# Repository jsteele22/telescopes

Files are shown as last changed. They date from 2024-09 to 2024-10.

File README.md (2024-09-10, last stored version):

# Notes on using CC portable telescopes.

There are many possible combinations of equipment that can be used
together; eg, tripod, mount, OTA, camera,...

The approach used here will be to document each item in separate
pages.  For a given combination of equipoment, a \"manual\" can be
constructed by combining the relevant pages.

A few standard combinations are presented here.

## Mounts with Field Tripods

* [Skywatcher EQ6-R Pro](docs/mount/eq6.md)
* [Losmandy G11](docs/mount/losmandy.md)
* [Celestron](docs/mount/celestron.md)

## Optical Tube Assemblies (OTAs)

* [Celestron 8\"](docs/ota/celestron8.md)
* [Meade 8\"](docs/ota/meade8.md)
* [Meade 10\"](docs/ota/meade10.md)
* [Lunt Solar telescope](docs/ota/lunt.md)

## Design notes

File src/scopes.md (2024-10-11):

# Portable Telescopes

## Standalone telescopes
Simple all-in-one approach.

* [UniStellar eVscope](standalone/evscope.md)
* [Dobsonian Telescopes](standalone/dobs.md)

## Component Telescopes
Combine components to form a complete system.

* An [optical tube assembly (OTA)](otas/index.md) gathers and focuses the light.
* A [mount](mounts/index.md) points the OTA in the right direction.
* A [pier adapter](pier/index.md) alows a mount to be used on a fixed pier.

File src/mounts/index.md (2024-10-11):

# Telescope Mounts

The following mounts are available.  Each includes a tripod for field
use and a pier adapter for use on our observatory deck.

* [Skywatcher EQ6-R Pro](eq6/index.md) The newest mount, and best
  choice for general purpose use.  This mount has a USB port and can
  be controlled by a Windows computer or the hand controller.

* [Losmandy G11](losmandy/index.md) The strongest of our mounts and
  very well made.  This mount has a custom stepper motor system and an
  open-source (**OnStep**) controller.

* [Celestron EQ5](eq5/index.md) (aka EQ5) An older, lighter-weight
  mount. This mount has a custom stepper motor system and an
  open-source (**OnStep**) controller.
  
## Using OnStep

Two of the above mounts have **OnStep** control systems.  Since the
systems are very similar, they will be [explained together
here](using_onstep/index.md).

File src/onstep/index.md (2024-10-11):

# OnStep

**Onstep** is an open source hardware/software project to provide
smart telescope features (e.g., alignment, GoTo) to an otherwise
un-smart or even unmotorized telescope.

For general information about OnStep, go to [the OnStep project
homepage](http://onstep.groups.io/g/main/wiki/3860).

Two of our telescope mounts have been converted for use with
OnStep. Information regarding these particular OnStep conversions is
provided here:

* Details that are [common to both mounts](shared/index.md) 

* Details specific to the [Losmandy G11](g11/index.md) mount

* Details specific to the [Celestron EQ5](eq5/index.md) mount.

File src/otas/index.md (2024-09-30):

# Optical Tube Assemblies
All of these OTAs have a an aluminum dovetail bar that mates with any
of our mounts.

### [Lunt H-alpha](lunt/index.md)
A dedicated solar telescope.

### [Celestron 8"](c8/index.md)
Our newest and best optical telescope.

### [Meade 8"](meade8/index.md)
OTA removed from an old Meade LX200.

### [Meade 10"](meade10/index.md)
OTA removed from a an old Meade LX200.

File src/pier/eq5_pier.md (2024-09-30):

# Pier Adapter for Celestron EQ5 Mount.

The EQ5 mount is *much* sturdier on a pier than on it's tripod!

## Required

The following items are stored in the glass case by the Observatory
double doors:

* EQ5 **Pier Adapter**: a cylinder of unfinished aluminum, with a
  protruding tab on top.

* EQ5 **Pier Adapter Rod**: A chromed metal rod with threads on one
  end and an aluminum knob on the other.

## Setup

* Place the adapter above the large hole towards the northern end of
  the pier shelf.

* Orient the adapter so that the **azimuth adjustment post** on top is
  to the North.

* Try inserting the theaded end of the adapter rod through the large
  hole on the underside of the pier shelf. With the rod perfectly
  vertical, it should pass upwards through the very center of the pier
  adapter.

* Look at the base of the EQ5 mount and locate the the pair of screws
  with black plastic knobs. These are the **azimuth adjustment
  screws.**

* Look at the underside of the EQ5 mount an loosen both screws until
  there is plenty of space between them: an inch or 2-3 cm is good.

* Gently place the EQ5 mount on the pier adapter, being sure that the
  tips of the azimuth adjustment screws pass on either side of the
  azimuth adjustment post.

* As before, pass the threaded pier adapter rod from below the pier
  shelf up through the adapter and get it threaded into the mount.

* Screw in the rod until it is close but not all the way in.

* Slowly start to tighten the rod, being sure to wiggle the
  adapter/mount slighly. It is important that the adapter centers
  itself and all parts are vertically aligned.

* Tighten the rod until it is **snug, but not tight**.

Everything else follows the normal setup and alignment procedures for
the mount.

## Takedown

Be sure to return the Pier Adapter and the threaded Pier Adapter Rod to their
correct storage spot: the glass case by the double doors of the
observatory.

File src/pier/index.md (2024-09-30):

# Pier mountings

Just outside the double doors of the Barnes Observatory is a metal
pier that can be used instead of a tripod with some of our telescope
mounts.

The only difference from normal (tripod) use of the mount lies in the
special adapter needed.

* [Losmandy Pier Adapter](losmandy_pier.md)
* [Celestron EQ5 Pier Adapter](eq5_pier.md)

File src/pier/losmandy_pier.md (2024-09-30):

# Pier Mount for Losmandy G11 Mount.

This is a great combination: our sturdiest mount on our sturdiest support.

## Required :

These should all be stored together in the glass case by the double
doors of the Observatory:

* The Losmandy pier adapter (black anodized aluminum.)
* Threee hex screws **kept with the pier adapter at all times.**
* T-handle hex driver **kept with the pier adapter at all times.**

## Setup:

* Line the adapter up with the appropriate threaded holes in the
  pier. The little tabs for mounting the control electronics should
  point to the South.

* Get all 3 screws started.

* Screw all 3 screws to just barely touching the bottom.

* Tighten all 3 screws a **little bit snug.**

* Return the T-handle hex driver to its storage place.

The adapter is identical to the top of the Losmandy tripod, so
remainder of setup proceeds as usual.

## Takedown

* Remove the three screws.

* Return the adapter, the three screws, and the T-handle nut driver to
  their storage place.

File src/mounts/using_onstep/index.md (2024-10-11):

# Using OnStep

## Why are you here?

Do you **need** to know anything about OnStep?

Our two OnStep telescope mounts are configured to begin tracking at
sidereal rate as soon as they are powered on.  If you don't plan to
use any smart telescope features like software star alignment or
finding a target, then you cn skip the rest and start observing.

Just point the telescope at an object.  If you were precise enough
while setting up the mount, the object should remain in view for a
while.

For everyone else, keep reading.

## Background

The most basic functions of the OnStep controller attached to the
telescope are:

* **Star Alignment:** gathering data on where the stars *really* are,
  and using this data to correct for imperfect mount alignment or
  configuration inputs.

* Keeping track of the telescope's position as it moves.

* Moving the scope, either in response to user input or to track
  objects as they move across the sky.

* Communication, whether it be with other electronics, a computer
  program, or even a human.

There are *many, many* ways to access and use OnStep.  Here we will
present a limited range of options to keep things manageable. Even so,
it helps to scan the material first to get a broad overview and then
decide where to focus for more detail.

Broadly speaking, you can connect to the telescope (i.e., the OnStep
controller) in two different modes.  This is not official OnStep
terminology, just a distinction that helps organize your approach to
using Onstep.

* **User Mode**, where a generic program (e.g., Stellarium) talks to
  the scope, but with limited features. This could even include
  simplistic use cases like a passive hand controller.

* **Control Mode**, where an OnStep-specific program has full control
  of (nearly) every possible feature.

Example: Stellarium is a great *user mode* program.  In addition to
its planetarium features, it can control and display the scope's
position and send data to the scope to update its star alignment.
This is almost all you need for a night of observing.  But Stellarium
cannot, for example, turn tracking on/off, switch to solar tracking,
park the telescope, change the slew rate, verify or change the time,
etc.  For that you will need a *Control Mode* program.

Note: It is fine to use different devices for control mode and user
mode access; e.g, an Android phone for control and a laptop for a user
program.  It is fine if both devices are connected simultaneously, but
they don't have to be; you could adjust a few settings from your phone
and then disconnect, then fire up software on your laptop for the rest
of the evening.

## Prerequisites (all use cases):

* The mount is set up and mechanically aligned.

* The OTA is installed and balanced.

* With **power off**, the scope is placed (precisely!) in **Home
  Position**.

## Power Up

Now, power on the controller.  There is no switch, just plug in the
power cable.

From now on, **do not move the scope manually** (i.e., by loosening
the clutches and pushing).  This would confuse the controller.

If anything goes wrong (power glitch, someone moves the cope manually)
just go back to Home position and do a power cycle.

## Establish Control Mode Access.

Choose one of the [options for Control Mode Access](control_mode.md)

## Are You Through Yet?

You might be ready to start observing.  There are a few options for
controlling the telescope without any additional software.

* You can just slew to objects you see in the sky.  For the slewing
  controls, you can use the web interface, the Android app, or a
  passive hand controller. (Check for hand controller directions
  before pluging anything in!)

* You can just enter coordinates for objects you want to observe using
  the web interface or the Android app. When you are centered on an
  object, you can update the star alignment.

* You can choose objects from a catalog in the Android app.  (The web
  interface also has this feature, but it needs updating to work.)

* A smart hand controller could be an option.  We don't have one yet,
  but stay tuned.

For anything more than the (not very polished) solutions above, you'll
probably want to use some user-friendly software.

## Prepare OnStep for User Mode Software.

Learn about [how user mode software talks to OnStep.](user_mode.md)
There may or may not be some steps you need to take.

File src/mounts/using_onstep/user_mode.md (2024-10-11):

# User Mode Software: Connecting to OnStep

To connect user mode software to OnStep, there are two choices to be
made:

## Hardware Connection : USB or WiFi

You have already seen how to connect to OnStep using WiFi.  You can
just use that method if it works for you.

But for User Mode connections, there is a new, much simpler option:
Just use a USB cable.  In my experience, this is by far the simplest
and most reliable method.

The USB connection works for Window, Linux, and Mac. For your OS, be
sure you know how to identify the connection after the cable is pluged
in.

## Software Connection : Direct, ASCOM, (INDI/INDIGO ?)

### Direct Serial Connection

If you are using a USB cable, then the OnStep controller acts just
like a Meade LX200 telescope.  This is an old, very popular telescope
and many user programs (including Stellarium) know how to talk
directly to it.

If you are using a Mac, this is the option for you.

### Using ASCOM

ASCOM is a software platform (**for Windows only**) that makes
astronomy programs work together.  Any user program (like Stellarium)
that supports ASCOM, will work with any instrument that supports
ASCOM; this includes not only our OnStep mounts, but also our
Skywatcher EQ6-R Pro mount, and other goodies as well (focusers,
cameras, ...)

With OnStep, ASCOM provides access to many more features, meaning less
need to mess around with control mode software.

If you plan to use your Windows computer with a telescope more than
one time, I recommend that you [set up ASCOM on your
computer.](ascom_setup.md)

### INDI/INDIGO

INDI and INDIGO are two identical-ish alternatives to ASCOM.  The goal
is to make something that works on any computer. It/they are much
newer and much more ambitious than ASCOM, so there seem to be more
rough edges and hiccups.

There are reports that it works with MacOS/Stellarium/OnStep.
However I have never tried this.

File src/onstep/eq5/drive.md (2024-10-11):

# Drive System for the EQ5 Mount

## Description

The DC gearmotors that came with the mount were removed. For each
axis, this left a worm drive with a ratio of 144:1.  This ratio is
still a bit high for fine control, so a further reduction was
introduced using toothed fan belts and pulleys. Using commonly
available pulleys with 16 and 60 teeth, 400-step stepper motors, and
16 microsteps, the final drive ratio is:

[(60/16) \* 400 \* 16 \* 144]/360 = 9600 microsteps per degree of axis rotation

## Details

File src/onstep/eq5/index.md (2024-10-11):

# Celestron EQ5 Onstep Conversion

## Background 

Our Celestron mount was purchased with the model name AS-GT. This
rather short-lived model was identical to the widely known EQ5 mount,
with the addition of a GoTo system.  Unfortunately, the AS-GT
electronics self-destructed during a firmware upgrade, so our mount
essentially became an EQ5.

## Drive Drain Description

For both axes, the drive train consists of a 400-step NEMA 17 stepper
motor, a right-angle NEMA 17 mounting bracket, and a belt drive
reduction consisting of GT2 standard 6mm wide timimng belt and pulleys.

Using 16 and 60 teeth pulleys, the 144:1 gear reduction of the worm
drives, and 16 microsteps per step gives us:

[400 \* 16 \* (60/16) \* 144]/360 = 9600 microsteps per degree of axis rotation.

## Adapters

Attaching drives to the EQ5 mount, which was not originally designed
to be motorized, is a bit tricky.  In this design, we use stock
right-angled motor mounts and a custom 3D printed adapter. For each
axis the adapter is different and the length of the timing belt is
different.  The adapters take advantage of existing holes in the EQ5
mount; no orinal hardware was modified.

The drive system was designed in OpenSCAD.  The [OpenSCAD source
code](Celestron_ASGT.scad) is used to generate the STL files for the
[RA adapter](eq5_ra_plate.stl) and the [Dec adapter](eq5_dec_plate.stl).

For the electrical connection to the motors, a housing was designed to
hold an RJ45 breakout board to the rear end of the motor. As before,
the [OpenSCAD source file](nema_cap.scad) was used to generate the
[STL file](nema_cap.stl) for 3D printing.

## Purchased Parts

All of the following purchased on Amazon.

* [NEMA 17 stepper motor](stepper.pdf)
* [NEMA 17 right angle bracket](bracket.pdf)
* GT2 pulley, 6mm wide, 16 teeth, 5mm bore
* GT2 pulley, 6mm wide, 60 teeth, 6mm bore
* GT2 timing belt, 6mm width, 180mm length, 90 teeth. (Declination) 
* GT2 timing belt, 6mm width, 158mm length, 79 teeth. (RA)

##  Additional upgrades to the EQ5 mount

* 3D printed [upper cover](eq5_polar_cover_upper.stl) for the polar scope.

* 3D printed [lower cover](eq5_polar_cover_lower.stl) for the polar scope.

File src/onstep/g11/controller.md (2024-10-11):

# MaxPCB4 Controller, Losmandy G11 details

The Losmandy mount uses the MaxPCB4 controller board.  This board is
configured as follows

* Teensy 4.1 microcontroller.

* TMC 2130 V3.0 motor driver modules (Amazon) for RA and Dec. These
  axes have RJ45 (e.g. Ethernet) socket outputs.  Conection to the
  corresponding stepper motors is via standard RJ$% patch cables.

* Two addional axes (focuser, etc.) not currently implemented.

* **Put a link to software config.**

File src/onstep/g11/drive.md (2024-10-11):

# Losmandy G11 Drive System.

## Background

On the stock G11, each axis had a DC gearmotor coupled to a worm gear
drive. The worm gear ratio is 360:1; i.e., a complete revolution of
the motor outut rotates the axis by 1 degree.

For the OnStep conversion, the original motors and couplers were
removed and the new NEMA 17 stepper motors installed using custom 3D
printed adapters. No physical modifications were made to the mount.

**Note**: The stepper motor take 400 full steps per revolution.  They are
run at 256 microsteps per step.  Thus, the final drive ratio is :

(400 \* 256 \* 360)/360 = 102400 microsteps per degree of axis
revolution.

## Worm Drive Coupler

The new stepper motors have a 5mm D output shaft.  The Losmandy worm
drive has a 1/4' (6.35 mm) input shaft.  For this application a
flexible coupler was purchased from Amazon. ("5mm to 6.35mm Shaft
Coupling 25mm Length 18mm Diameter")

Although the shaft diameters of this coupler are correct, the OD of
the coupler (18mm) is too large to enter the Losmandy worm gear
housing.  Thus, on the 1/4" end of the coupler, the OD had to be
machined down a bit  for clearance.

**Note**: Fasteners on the Losmandy mount are *inch*, not metric.

**Note** Each worm drive is protected by a rectangular cover. These
  can be removed using a 1/16" hex wrench to *loosen* (not remove) two
  tiny set screws. **Do not** loosen or adjust any other part of the
  worm drive system!

## Motor Adapters

The stepper motors are attached to the G11 using 3D printed adapters.
The adapters use the same threaded holes in the G11 mount as the old
motors.

In addition to positioning the stepper motors, the adapters provide an
enclosure for a small RJ45 breakout PCB purchased on Amazon. (Teansic
5 PCS RJ45 Connector Breakout Board 8-pin Headers Network Port
Adapter).  The stepper wire to RJ45 pin mapping matches the RJ45 ports
on the MaxPCB4 OnStep controller.

## Motor Adapter Design.

The adapters were designed in OpenSCAD. The .scad files contain the
source code for the design.  The OpenSCAD program is used to generate
.stl files for 3D printing.

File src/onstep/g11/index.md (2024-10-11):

# Losmandy G11 OnStep Conversion

## Background

Our Losmandy G11 mount came with feeble DC gearmotors that were
intended only for for.  The mount could neither slew nor perform
GoTo moves.  There was no means of keeping track of celestial
coordinates.

The addition of powerful stepper motors made it possible to control
the mount using OnStep.

# Details

Information pertaining to the G11 OnStep conversion:

* The [NEMA 17 stepper motors](17HM19-2004S.pdf) used for the G11 mount.

* The [motor drive system](drive.md), including info on 3D
  printed parts

* [CAD files](CAD/index.md) for 3D printed parts.

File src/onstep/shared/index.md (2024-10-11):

# OnStep Conversion Details

## TO DO: decide on V_in and Voltage regulation.

The following information pertains to the OnStep conversion of both
the Losmandy G11 and Celestron EQ5 mounts.

## The Firmware: OnStepX

The heart of OnStep is the firmware.  As the OnStep project matured, a
bottom-up re-write of the firmware called **OnStepX** was released.
This is the firmware we use.  Don't confuse it with the older
firmware, called simply OnStep.

For the purposes of configuring and building OnStepX for our telescope
mounts, I made a fork of the OnStepX github repository.  That repo can
be found [HERE](https://github.com/jsteele22/OnStepX), and should be
consulted for any further firmware details.

## The Controller: MaxPCB4

The firmware must run on a *dedicated* microcontroller which can
directly control the motors on the mount.  So the other heart of
OnStep is a **controller board** which at minimum provides a
microcontroller, at least two motor drivers, and some means of
communication with the user.

There are many different controller boards available which meet these
requirements.  The one we use is the **MaxPCB4**.  This board was
designed specifically for the OnStep project and it only runs the
OnStepX firmware.

Some public information about the MaxPCB4:

* [General information ](http://onstep.groups.io/g/main/wiki/33523)

* [PCB design](http://oshwlab.com/hdutton/maxpcb4/)

* [Kits for sale here](http://graydigitalarts.com/product/maxpcb4)

# Controller Hardware Options

There are various hardware options when assembling the MaxPCB4
controller.  Below are the *hardware* configuration we currently have.
For firmware configuration options, see the github repository
referenced above.

* PCB version : MaxPCB4.01

* Microcontroller module: Teensy 4.1

* Battery backup option: installed.

* Power switch: no

* Axes 1 and 2 (Ra, Dec) motor controllers : TMC2130 v3.0 modules
  purchased from from vendor BIQU on Amazon. These are SPI
  controllers.

* Axes 1 and 2 jumpers: set for SPI mode

* Axes 1 and 2 (RA, Dec) output connector: RJ45.

* Axes 3 and 4 motor controller: not installed (yet)

* Axes 3 and 4 jumpers: not populated.

* Axes 3 and 4 output connector: RJ22 (6P6C modular jack.)

* Axes 3 and 4 voltage: same as Axes 1 and 2.

* DB15 auxilliary connector:  not populated.

* ST4 interface: RJ12 socket installed, +5V jumper **not** installed.

* WeMos D1 socket : ESP8266 WeMos Mini Pro (provides WiFi, no
  Bluetooth.) Currently running the OnStep Smart Web Server (SWS)

* Buzzer: not installed. (requires *active* piezo buzzer.)

## Potential Hardware Configuration Changes:

* Use Axis 3 (or 4) to control focuser on Lunt solar telescope.

* Install an active buzzer.

* Replace Wemos module with WeMos ESP32 D1 Mini, to provide Bluetooth
  capability.

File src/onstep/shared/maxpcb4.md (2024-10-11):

# MaxPCB4 Onstep Controller Board.

Many different controller boards can run OnStep firmware.  The
specific one used for our mounts is the
[MaxPCB4](http://oshwlab.com/jdutton/maxpcb4).

More info to go here eventually.

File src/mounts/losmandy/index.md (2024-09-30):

# Losmandy G11

The Losmandy G11 is an exremely well-made and strong mount. It is
great when using telescope with a camera.

The extremely limited controller that came with this mount has been
replaced with more powerful stepper motors and an OnStep controller
that allows for computer control.

* [packing](losmandy_packing.md)
* [setup](losmandy_setup.md)

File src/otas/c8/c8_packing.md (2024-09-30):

# Packing List: Celestron 8" OTA

* Pelican case with OTA.
* 2" Star Diagonal in original box.  (Posisbly inside Pelican case.)
* Appropriate 2" eyepieces.

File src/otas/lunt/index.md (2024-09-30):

# Lunt H-alpha Solar Telescope

A small refractor telescope with an extremely sharp, tunable filter
for observing the Suns H-alpha line.

* [Packing List](lunt_packing.md)
* [Setup](lunt_setup.md)
* [Usage](lunt_usage.md)

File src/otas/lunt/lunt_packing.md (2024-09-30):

# Packing List for Lunt Solar OTA

The following items should be in the aluminum case:

* Lunt H-alpha OTA
* metal lens cover, screwed into OTA
* _Sol Searcher_ finder, atached to OTA
* Diagonal _B1200_, attached to OTA
* aluminum dovetail bar, attached to OTA
* 1-1/4" eyepieces: 10mm, 25mm
* black cloth to cover head

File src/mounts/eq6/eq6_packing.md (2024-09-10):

# Packing List : Skywatcher EQ6-R Pro

## Items to Pack:

* White tripod
* 2 white counterweights.
* Goal Zero power bank (Only usable power source ATM...)
* Pelican case with mount and accessories.

## Contents of Pelican Case:

* EQ6-R Pro mount
* Spider (stored vertically, in front of case.)
* 2x Azimuth adjuster bolts
* Hand controller with cord.
* Power cord.

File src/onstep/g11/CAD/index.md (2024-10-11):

# CAD Files for G11 OnStep Conversion

## Stepper Motor Adapters

The stepper motor adapters were designed in OpenSCAD. Here is [the
OpenSCAD source code](losmandy1.scad) and here are the [STL
files](mount_stl/index.md).

## Controller Board Enclosure

The MaxPCB4 controller is enclosed in a housing which attaches to the
G11 mount in the same way as the original controller.

It was designed using [OnShape](http://www.onshape.com), a free web-based CAD
program.  Here are the [STL files](enclosure_stl/index.md) for the enclosure.

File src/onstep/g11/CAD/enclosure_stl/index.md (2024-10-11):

# STL files for MaxPCB4 enclosure, Losmandy version

* [base](losmandy_base.stl)
* [lid](losmandy_lid.stl)
* [left panel](losmandy_panel_l.stl)
* [right panel](losmandy_panel_r.stl)
* [plug for nut](losmandy_plug.stl)

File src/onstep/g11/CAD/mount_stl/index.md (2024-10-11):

# Stepper Motor Mounts for Losmandy G11

* [adapter plate](losmandy1_plate.stl)
* [cover](losmandy1_cover.stl)

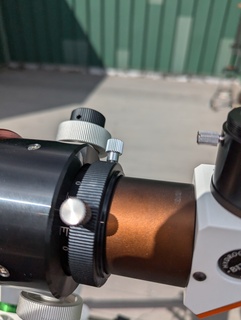
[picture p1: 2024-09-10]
src/media/pub/lunt_ota_extended.jpg

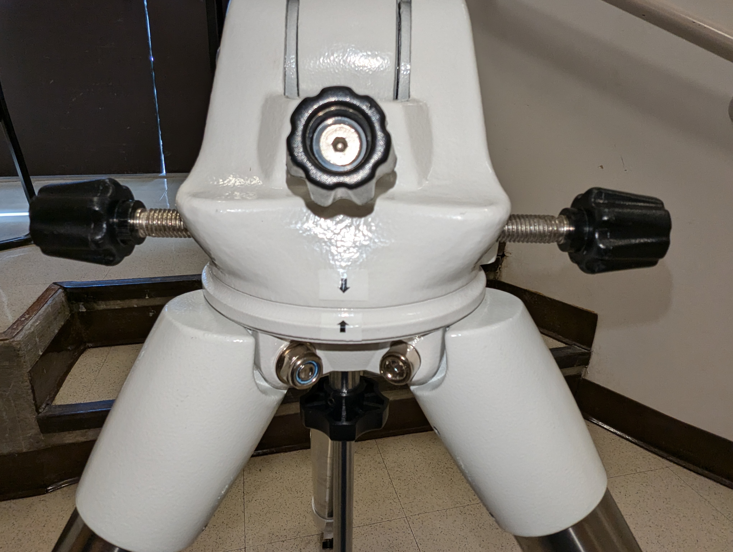
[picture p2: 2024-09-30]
mkdocs_astro/website_src/media/incoming/.trashed-1728593634-PXL_20240910_205335041.jpg

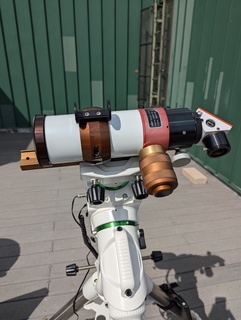
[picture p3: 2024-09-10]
src/media/pub/lunt_ota_mounted.jpg

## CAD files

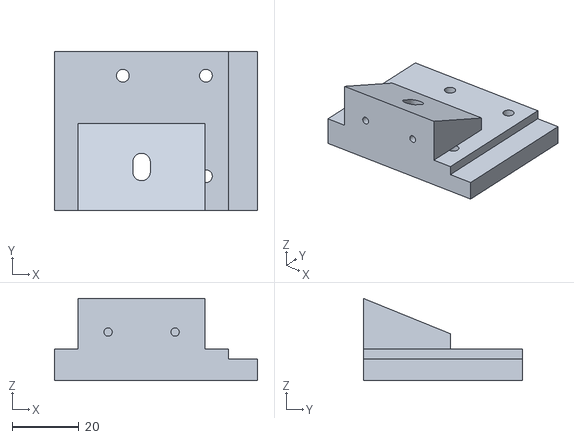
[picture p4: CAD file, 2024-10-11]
src/onstep/eq5/eq5_ra_plate.stl
60.6 x 47.5 x 24.5

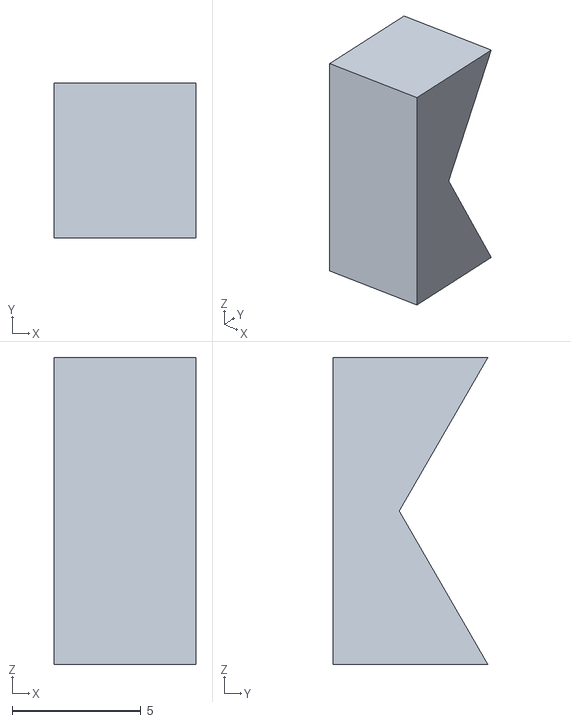
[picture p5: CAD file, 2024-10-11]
src/onstep/g11/CAD/enclosure_stl/losmandy_plug.stl
5.50 x 6.00 x 11.9

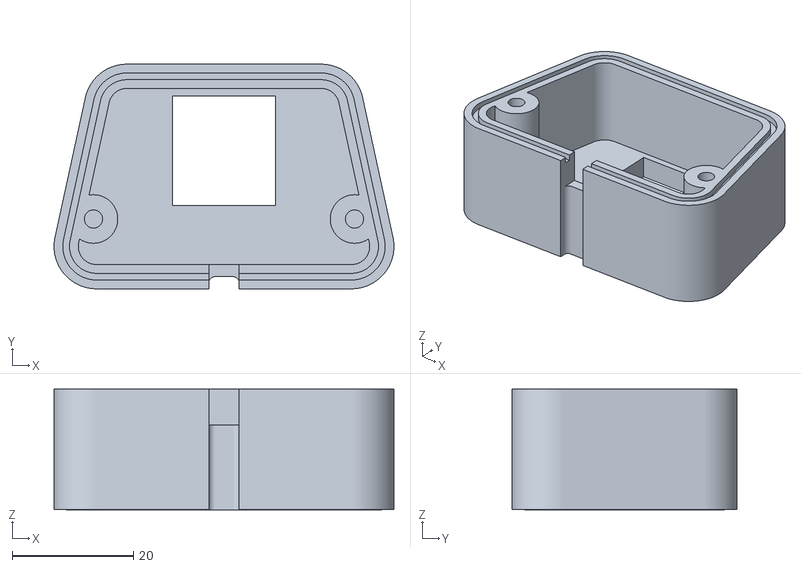
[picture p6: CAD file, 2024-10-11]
src/onstep/g11/CAD/mount_stl/losmandy1_cover.stl
56.0 x 37.0 x 19.9

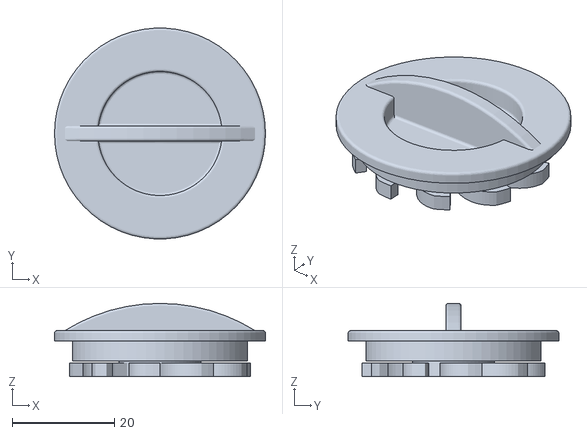
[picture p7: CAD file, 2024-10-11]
src/onstep/eq5/eq5_polar_cover_upper.stl
41.2 x 41.2 x 14.3

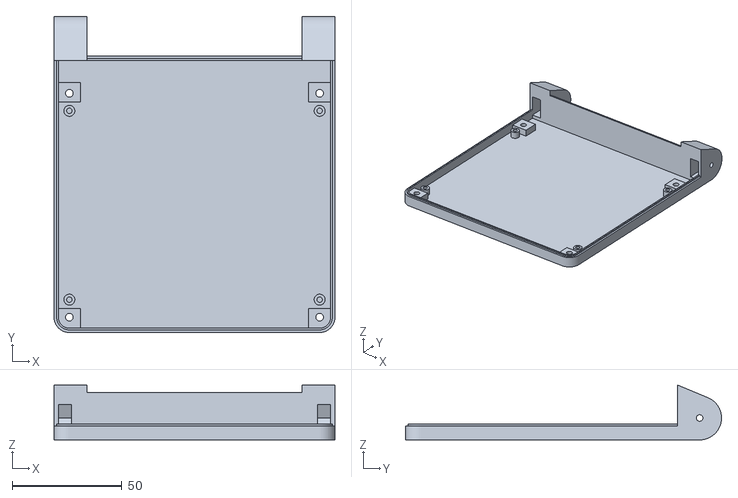
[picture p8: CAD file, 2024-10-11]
src/onstep/g11/CAD/enclosure_stl/losmandy_base.stl
128.0 x 144.0 x 25.0

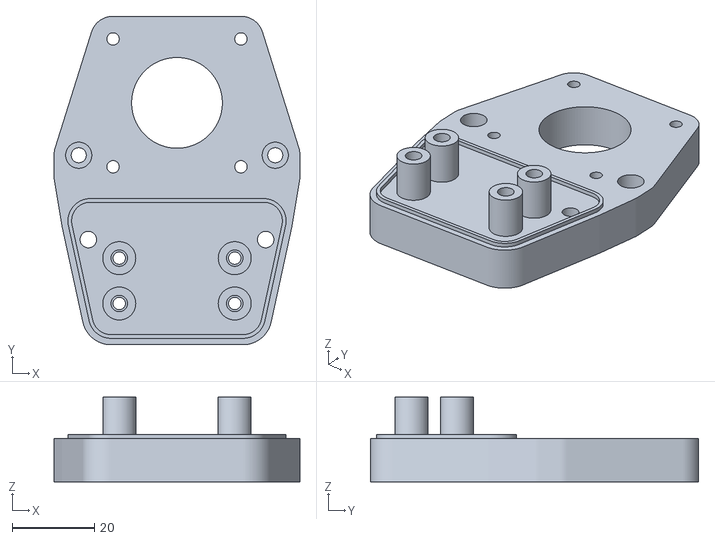
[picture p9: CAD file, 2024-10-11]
src/onstep/g11/CAD/mount_stl/losmandy1_plate.stl
59.6 x 79.7 x 20.5

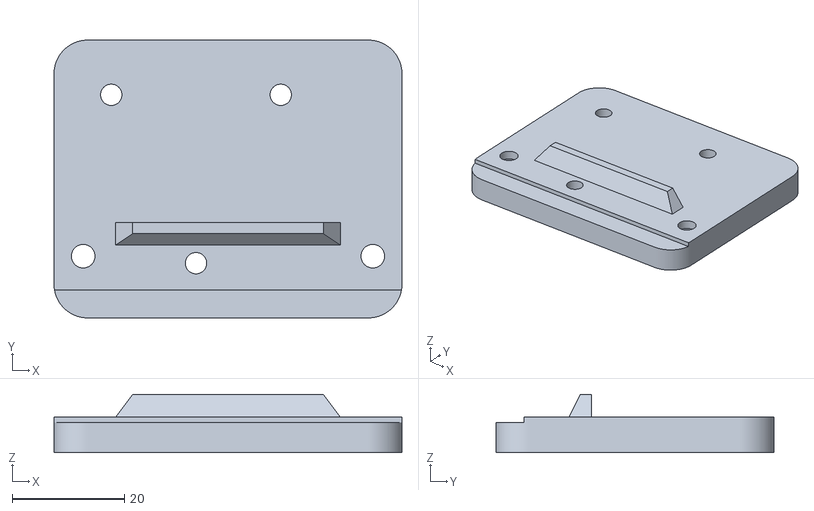
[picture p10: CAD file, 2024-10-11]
src/onstep/eq5/eq5_dec_plate.stl
62.0 x 49.5 x 10.3

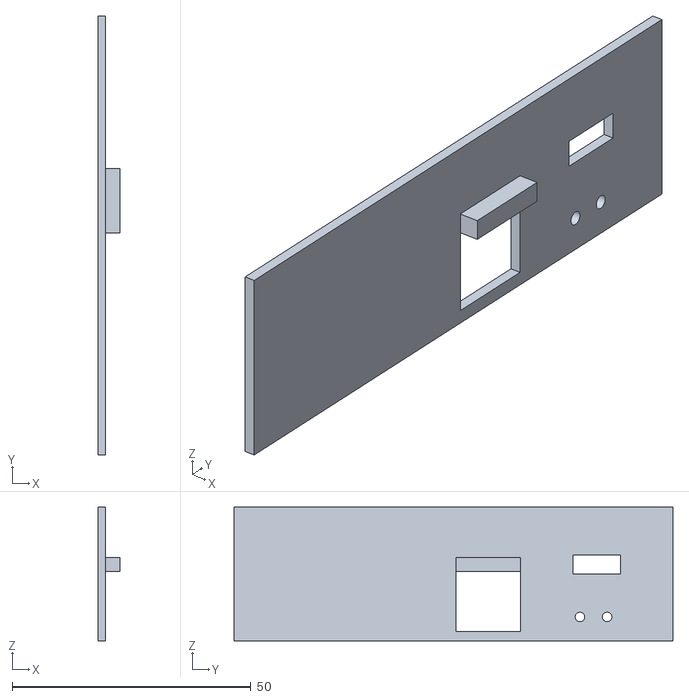
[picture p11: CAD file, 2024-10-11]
src/onstep/g11/CAD/enclosure_stl/losmandy_panel_l.stl
4.60 x 92.0 x 28.0

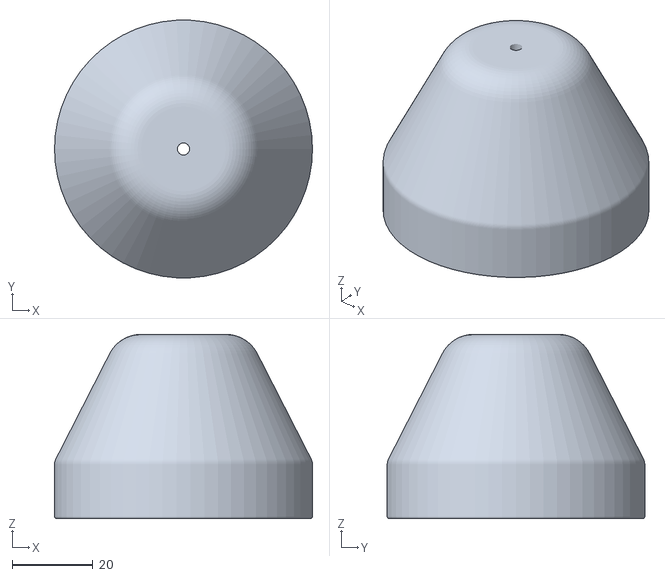
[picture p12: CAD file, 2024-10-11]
src/onstep/eq5/eq5_polar_cover_lower.stl
64.1 x 64.0 x 45.8

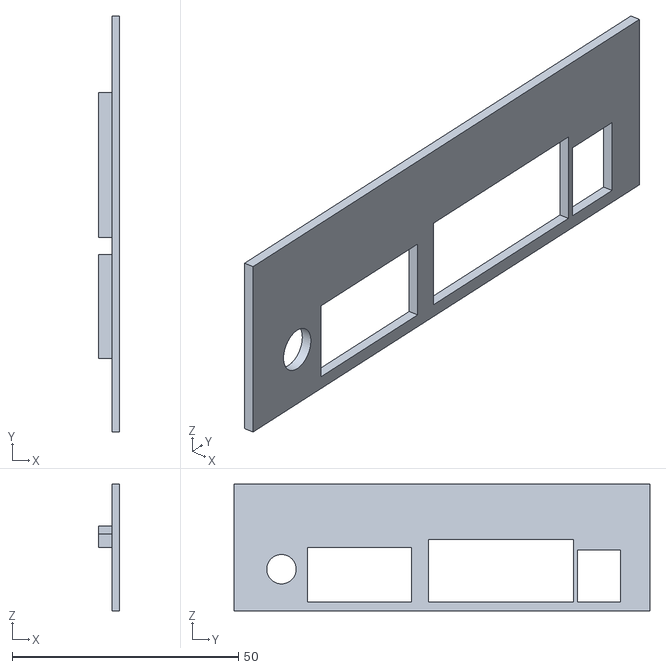
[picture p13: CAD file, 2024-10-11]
src/onstep/g11/CAD/enclosure_stl/losmandy_panel_r.stl
4.60 x 92.0 x 28.0

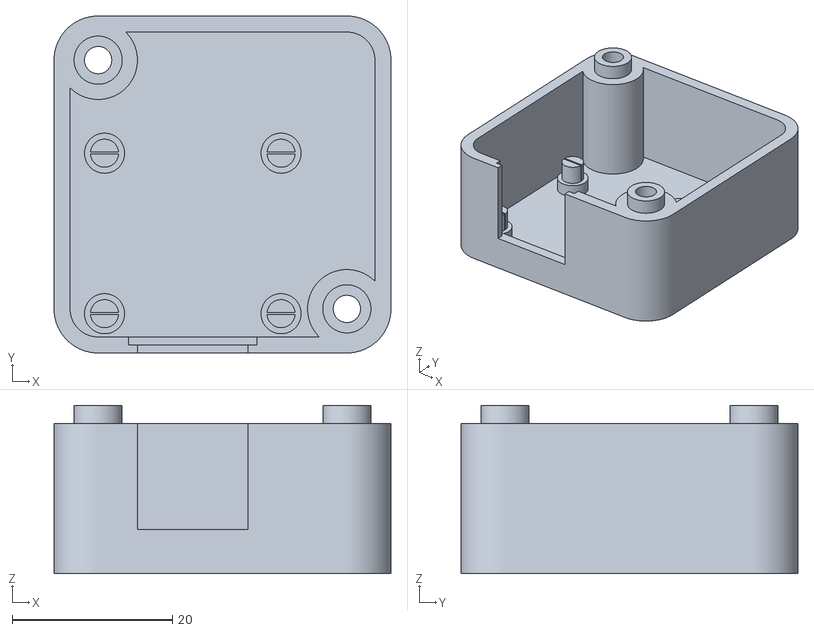
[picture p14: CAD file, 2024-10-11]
src/onstep/eq5/nema_cap.stl
42.0 x 42.0 x 21.0

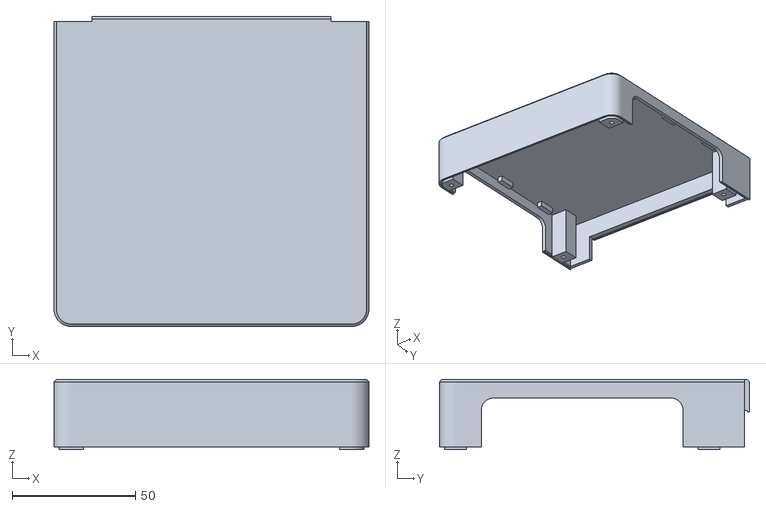
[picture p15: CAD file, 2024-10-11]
src/onstep/g11/CAD/enclosure_stl/losmandy_lid.stl
128.0 x 126.0 x 28.6

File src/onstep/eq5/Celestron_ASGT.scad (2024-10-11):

//Edits:
// reduce dp_z1, dp_z2 by 1 mm to loosen belt.


$fn = 100;

// Celestron AS-GT mount

// IDEA: create simple plates, attach NEMA brackets to them. 

// NEMA 17 bracket info

nb_t = 2.85;        // thickness of plate
nb_w = 49.5;        // perpendicular to motor axis
nb_l = 50.6;        // back of bracket to mount surface
nb_h = 51.4;        // top of bracket to bottom surface
nb_axis_h = 30.0;   // height of axis above bottom surface
nb_slot_w = 4.4;    // width of slots
nb_slot_sep = 30;   // dist betw slots
nb_slot_l = 34.2;   // length of slots
nb_slot_stop = 8.3; // meat betw slot and rear
                    // i.e., slots essentially centered
//nb_screw_d = 4.2;   // M4 screw, clearance
nb_screw_d = 3.8;   // M4 screw, tap
nb_nut_d = 7.0;     // FIXME:  slot width to capture nut


// RA plate

// Coordinate system:
//    origin on lower plate surface, centered on screw axis
//    +x to right
//    +y up along plate surface
//    +z up along screw axis

// RA late consists of two rectangular layers.
// Lower layer fits between casting ridges.
// Upper layer extends to the right for motor support. 
// Below the plate is a wedge that allows for (slight) +/- y
// adjustment for belt tension fine tuning. 

rap_x0 =  -26.0;            // x, left edge of both layers
rap_x1 =  +26.0;            // x, right edge of lower layer
rap_x2 =  +34.6;            // x, right edge of upper layer
rap_y1 = 13.0;              // y, upper edge
rap_y0 = rap_y1 - nb_w + 2; // y, lower edge (tiny bracket overhang) 
rap_z0 =    0.0;            // z, bottom of lower layer
rap_z1 =    3.1;            // z, lower/upper layer boundary
rap_z2 =    9.5;            // z, top of upper layer

// check: rap_z2 + nb_t >= mounting screw length (=12)

// location for NEMA bracket

rap_nema_adj = 0.5;     // ADJUST: tune RA center distance
rap_nema_y = rap_y1 - nb_w/2 - rap_nema_adj;
rap_nema_x = rap_x2;
rap_nema_z = rap_z1;

// location of RA worm axis

raw_y = 26.0;
raw_z = 36.0;

// location of RA motor axis

ram_y = rap_nema_y;
ram_z = nb_axis_h + (rap_z2 - rap_z0);

// calculate center distance
// Note: about 0.6 - 0.9 mm of slop from NEMA bracket slots

ra_cd = sqrt( pow(ram_y - raw_y, 2) + pow(ram_z - raw_z, 2) );
echo("RA center distance", ra_cd);


// check belt length

// gt2_60_16_160 = 39.5;
// gt2_60_16_158 = 38.4;


ra_screw_tap_d =    4.8;    // M5 screw, self tap
ra_screw_loose_d  = 5.2;    // M5 screw, easy passage
ra_nut_ffd = 7.9;           // flat-to-flat distance, M5 nut
ra_nut_h =  3.85;


module ra_nema_holes_2d() {
  x = rap_x2 - nb_l/2;
  dx = (nb_slot_l - nb_slot_w)/2; 
  y = rap_nema_y;
  dy = nb_slot_sep/2;  

  // 1 upper hole, 2 lower
  // manually optimize placement
  locs = [
    [ x + dx - 5, y + dy],
    [ x - dx,      y - dy],
    [ x + dx - 5,      y - dy]
  ];
    
  for (v=locs) {
    translate(v) {
      circle(d= nb_screw_d);
    }
  }
}

module ra_screw_2d(d=ra_screw_loose_d) {
  circle(d=d);
}

module ra_nut_2d(xtra=0.2) {
  // xtra=0.2 works great
  d = 1.155 * (ra_nut_ffd+xtra);  // diameter (circle of points)
  circle($fn=6, d=d);
}

// RA casting info

rac_ROC = 40.0;         // radius of RA cavity bottom
rac_screw_dy = 16.25;   // distance between screw and diameter
// calculate tilt angle of casting at screw axis
rac_theta = asin(rac_screw_dy/rac_ROC);

// RA wedge below plate, provides tension adjustability
// Center on screw axis.

raw_dx = 38.0;          // x size of wedge 
raw_dy = 26.0;          // y size of wedge
raw_dz = 9.75;          // z height of wedge on screw axis
raw_slot = 3;           // slot in y for screw hole
raw_adj_d = 2.5;        // horizontal pilot hole for adjusters
raw_adj_x = 10;
raw_adj_z = -5;         // z pos of adjusters 

module ra_wedge() {
  x = raw_dx/2;
  y = raw_dy/2;
  delta_z = y*sin(rac_theta);
  mirror([0,0,1]) {
    difference() {
      hull() {
        translate([-x, -y, 0]) {
          cube([raw_dx, 0.01, raw_dz - delta_z]);
        }
        translate([-x, +y, 0]) {
          cube([raw_dx, 0.01, raw_dz + delta_z]);
        }
      }
      hull() {
        hole_d = ra_screw_loose_d;
        translate([0, +raw_slot/2, 0]) {
          cylinder(d=hole_d, h=999, center=true);
        }
        translate([0, -raw_slot/2, 0]) {
          cylinder(d=hole_d, h=999, center=true);
        }
      }

      //adjuster holes
      for (x= [-raw_adj_x, +raw_adj_x]) {
        translate([x, 0, -raw_adj_z]) {
          rotate([-90,0,0]) {
            cylinder(d=raw_adj_d, h=999);
          }
        }
      }
    }
  }
}



module ra_plate_2d(x_right = rap_x1) {
  dx = x_right - rap_x0;
  dy = rap_y1 - rap_y0;

  difference() {
    translate([rap_x0, rap_y0]) {
      square([dx,dy]);
    }
    ra_nema_holes_2d();
  }
}


module ra_plate() {
  // lower level
  linear_extrude(height = rap_z1) {
    difference() {
      ra_plate_2d();
      ra_nema_holes_2d();
      ra_nut_2d();
    }
  }
  // upper level
  translate([0,0, rap_z1-0.001]) {
    linear_extrude(height = rap_z2-rap_z1) {
      difference() {
        ra_plate_2d(x_right = rap_x2);
        ra_nema_holes_2d();
        ra_nut_2d();
      }
    }
  }
  // wedge
  ra_wedge();

}


// DEC plate

// coordinate system:
// +x to right, 0 at center
// +y up along plate, 0 at center of mount holes
// +z up perp to plate, 0 at lower surface of plate.


dp_ROC = 6.0;           // corner radius of curvature
dp_xr =  +31.0;         // RH end of plate
dp_xl =  -31.0;         // LH end of plate
dp_yt =  +11;           // WARNING: 13mm max!!!
dp_yb =  dp_yt - nb_w;  // same width as NEMA bracket


// Adjust plate thickness (z2) for belt length.

dp_z0 =         0.0;        // bottom of plate

// belt was too tight
//dp_z1 =         3.0;        // height of mount screw through hole
//dp_z2 =         7.35;        // ADJUST:thickness of plate

dp_z1 =         2.0;        // height of mount screw through hole
dp_z2 =         6.35;        // ADJUST:thickness of plate

// 4.3 is a good minimum value 
echo("countersink", dp_z2 - dp_z1);


dp_dx = dp_xr - dp_xl;
dp_dy = dp_yt - dp_yb;

// two deck plate screws (M4) attach plate to mount

// 4.7 is too loose
dps_d  = 4.2;           // M4 clearance
dps_head_d = 8.0;       // clearance for head
dps_head_h = 3.9;       // height of cap screw head
dps_x = 25.8;           // disdt from center line

// calculate center distance for dec drive

dw_z = -12.5;               // dec worm_axle z
dw_y = -18.0;               // dec worm axle y

dm_z = dp_z2 + nb_axis_h;   // dec motor axle z
dm_y = dp_yt - nb_w/2;      // dec motor axle y

d_cd = sqrt( pow(dm_z - dw_z, 2) + pow(dm_y - dw_y, 2));
echo("Dec Center Distance", d_cd);

// Center distance for some pul1ey_pulley2_belt choices

gt2_60_16_158 = 38.42;
gt2_60_16_180 = 50.03;
gt2_60_16_200 = 60.37;


// a ridge to align dec plate to mount

module dp_ridge() {
  // make ridge as a hull of two rectangles, lower and upper
  dx_b = 40;
  dy_b = 4;
  dx_t = 34;
  dy_t = 2;
  dz =   4;

  rotate([ 0,180,0]) {
    translate([0,-dp_ROC, -0.01]) {
      hull() {
        translate([-dx_b/2, 0, 0]) {
          cube([dx_b, dy_b, 0.01]);
        }
        translate([-dx_t/2, 0, dz]) {
          cube([dx_t, dy_t, 0.01]);
        }
      }
    }
  }
}


// holes for mounting plate to mount
module mount_holes_2d(d=dps_d) {
  for (x = [-dps_x, +dps_x]) {
    translate([x, 0]) {
      circle(d=d);
    }
  }

}



// Place 3 holes to mount NEMA bracket to dec plate..
// NEMA mount face referenced to dec plate left edge.

module dp_nema_holes_2d(d=nb_screw_d) {

  xadj = 0.0;                   // fine tune x alignment
  
  xmid = dp_xl + nb_l/2;        // reference x to left edge
  ymid = (dp_yt + dp_yb)/2;     // y centered on plate 
  dx = nb_slot_l/2 -2;          // end of slot - screw diam/2
  dy = nb_slot_sep/2;           // half slot separation

  // locations of holes
  locs = [
    [ xmid - dx, ymid - dy],
    [ xmid + dx, ymid - dy],
    [ xmid,      ymid + dy],
  ];

  for (v=locs) {
    translate(v) {
      circle(d=d);
    }
  }
  
}

// plate profile is rectangle with rounded corners
module dp_main_2d() {
  xl = dp_xl + dp_ROC;
  xr = dp_xr - dp_ROC;
  yb = dp_yb + dp_ROC;
  yt = dp_yt - dp_ROC;
  locs = [
    [xl, yb],
    [xl, yt],
    [xr, yt],
    [xr, yb],
  ];
  hull() {
    for (v=locs) {
      translate(v) {
        circle(r=dp_ROC);
      }
    }
  }
}

// dec plate body
module dp_main() {
  // lower level: mount screw clearance, bracket hole tap
  linear_extrude(height = dp_z1-dp_z0, convexity=10) {
    difference() {
      dp_main_2d();
      mount_holes_2d(d = dps_d);
      dp_nema_holes_2d(d = nb_screw_d);
    }
  }
  // upper level: mount screw countersink, bracket hole tap
  translate([0,0,dp_z1 - 0.01]) {
    linear_extrude(height = dp_z2-dp_z1, convexity=10) {
      difference() {
        dp_main_2d();
        mount_holes_2d(d = dps_head_d);
        dp_nema_holes_2d(d = nb_screw_d);
      }
    }
  }
}
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

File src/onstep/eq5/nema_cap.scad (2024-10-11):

$fn=100;

// Connector housing that attaches to rear face of a NEMA motor.
// Replace 2 of 4 NEMA body screws with replacements that are longer. 


// use comments to select motor size

// NEMA 17
  nema_face_xy = 42/2;           // x,y position of face edge
  nema_screw_xy = 31/2;          // x,y of screw 
  nema_backplate_l = 9.0;       // thickness of rear plate of motor
  nema_screw_d = 2.8;           // M3 screw 
  nema_screw_loose_d = 3.4;     // M3 screw 
  nema_screw_inset_h = 2.5;     // depth of countersink
  nema_screw_inset_d = 6.6;     // diam of countersink
  nema_screw_l = 40;            // stock screw length
  nema_long_screw_l = 60;       // replacement screw length
  nema_extension_l =            // extra screw length available
    nema_long_screw_l - 
    nema_screw_l;



// NEMA 8
/*
  nema_face_xy = 20/2;
  nema_screw_loose_d = 2.2;    // M2 screw 
  nema_face_roc = 2;            // radius of curvature
*/


nema_face_roc =  nema_face_xy
               - nema_screw_xy;   // body corner radius of curvature 

wall_t = 2.0;                   // thickness of wall
lid_t = 2.0;                    // thickness of lid
  

// Connector is modeled as a simple box.
// It is placed upside down on rear face of motor.
// A pcb is placed above the connector, with a small
// clearance before the lid.

// connector shape/placement info

conn_shape = [
  15.75,        // x:width of connector face
  18.2,         // y:length front to back
  13.2          // z:height of connector face
];

conn_slop_x = 0.3;      // gap allowance on each side
conn_slop_z = 0.3;      // gap allowance on top

conn_inset = 1.0;       // setback from edge of motor
conn_base_z = 0;        // connector sits on motor

// location of center of connector
conn_loc = [
  -3.7,
  nema_face_xy - conn_shape.y/2 - conn_inset,
  conn_base_z + conn_shape.z/2
];

// pcb shape/placement info

pcb_shape = [
  28,            // width of side with connector
  25,            // length, front to back
  1.5           // thickness
];

pcb_inset = 1.4;    // pcb inset from connector front
pcb_standoff = 2;   // gap betw pcb and lid

// location of pcb center

pcb_loc = conn_loc + [
  0,
  +conn_shape.y/2 - pcb_inset - pcb_shape.y/2,
  +conn_shape.z/2 + pcb_shape.z/2
];

// pcb holes are symmetric about  centerline

pcb_hole_x = 11;    // half distance betw holes
pcb_hole_y = 10;    // half distance betw holes
pcb_hole_d = 4;

// 2d location relative to pcb center
pcb_hole_loc_2d = [
  [ + pcb_hole_x,    + pcb_hole_y,  0 ],
  [ + pcb_hole_x,    - pcb_hole_y,  0 ],
  [ - pcb_hole_x,    - pcb_hole_y,  0 ],
  [ - pcb_hole_x,    + pcb_hole_y,  0 ],
];


module pcb_holes_2d(d=pcb_hole_d) {
  translate([pcb_loc.x, pcb_loc.y]) {
    for (v=pcb_hole_loc_2d) {
      translate(v) {
        circle(d=d);
      }
    }
  }
}


module pcb() {

  difference() {
    translate(pcb_loc - 0.5*pcb_shape) {
      cube(pcb_shape);
    }
    translate(pcb_loc) {
      for (v=pcb_hole_loc_2d) {
        translate(v) {
          cylinder(d=pcb_hole_d, h=1000, center=true);
        }
      }
    }
  }
}


module connector(dx = 0, dy=0, dz=0) {
  shape = conn_shape + [dx, dy, dz];
  loc = conn_loc - 0.5*shape;
   // [-shape.x/2, -shape.y/2, -shape.z/2];
  translate(loc) {
    cube(shape);
  }
}


lid_z = pcb_loc.z + 0.5* pcb_shape.z + pcb_standoff;

// Bosses have a slotted nubbin pointing down
// through pcb holeand a post pointing up to lid.

module pcb_bosses() {

    
  d1 = pcb_hole_d - .5;    // nubbin diam
  h1 = pcb_shape.z *2;      // nubbin height

  d2 = pcb_hole_d + 1.0;    // post diam
  h2 = pcb_standoff;        // post height

  slot_w = 0.25;

  // start at top surface of pcb
  translate(pcb_loc + [0,0,pcb_shape.z/2]) {
    for (v=pcb_hole_loc_2d) {
      translate(v) {
        // nubbins
        translate([0,0, - h1]) {
          difference() {
            cylinder(d=d1, h=h1);
            // slots
            translate([-500, -slot_w/2, -500]) {
              cube([1000, slot_w, 1000]);
            }
          }
        }
        // posts
        cylinder(d=d2, h=h2);
      }
    }
  }
}

module wall_2d() {
  difference() {
    nema_face_2d();
    nema_face_2d(r=nema_face_roc -wall_t);
  }
  difference() {
    nema_screws_2d(odd=false, d=2*nema_face_roc- 0.6*wall_t);
    nema_screws_2d(odd=false, d=nema_screw_loose_d);
  }
}

wall_h = lid_z;
module wall() {
  difference() {
    linear_extrude(height = wall_h, convexity=10) {
      wall_2d();
    }
    // inner cutout houses connector profile
    translate([0,0, 0]) {
      connector( dx = conn_slop_x,
                 dz = conn_slop_z);
    }
    // outer cutout provides retaining "window"
    translate([0, 2*conn_inset, 0]) {
      connector( dx = -2.0,
                 dz = 0);
    }
  }
}

module lid_2d() {

  locs = nema_screw_locs_2d();
  difference() {
    nema_face_2d();
    nema_screws_2d(odd=false);
  }
}

module lid(h = lid_t) {

  translate([0,0,lid_z]) {
    linear_extrude(height = h) {
      lid_2d();
    }
  }
}    

// Feet that protrude down into NEMA screw countersinks
// on back of motor.


module feet() {

  d = nema_screw_inset_d - 0.6;
  h = nema_screw_inset_h - 0.2;

  for (v=nema_screw_locs_2d(odd=false)) {
    translate(v) {
      difference() {
        translate([0,0,-h]) {
          cylinder(d=d, h=h);
        }
        cylinder(d=nema_screw_loose_d, h=1000, center=true);
      }
    }
  }
}


// 2d outline of motor body screw holes

function nema_screw_locs_2d(odd=true, even=true) = [
  if (even)
    [ +nema_screw_xy, +nema_screw_xy],      // top right
  if (odd)
    [ +nema_screw_xy, -nema_screw_xy],      // top left
  if (even)
    [ -nema_screw_xy, -nema_screw_xy],      // bottom left
  if (odd)
    [ -nema_screw_xy, +nema_screw_xy],      // botom right
];


module nema_screws_2d(d=nema_screw_loose_d, odd=true, even=true) {
   
  for (v=nema_screw_locs_2d(odd=odd, even=even)) {
    translate(v) {
      circle(d=d);
    }
  }
}

// 2d outline of motor face
module nema_face_2d(r=nema_face_roc) {
  hull() {
    nema_screws_2d(d=2*r);
  }
}


module motor_body() {
  h1 = nema_backplate_l - nema_screw_inset_h;
  h2 = nema_screw_inset_h;

  translate([0,0,-nema_backplate_l]) {
    linear_extrude(height = h1) {
      difference() {
        nema_face_2d();
        nema_screws_2d(d=nema_screw_loose_d);
      }
    }
  }

  translate([0,0,-h2]) {
    linear_extrude(height = h2) {
      difference() {
        nema_face_2d();
        nema_screws_2d(d=nema_screw_inset_d);
      }
    }
  }
}

module screw_extensions(d=nema_screw_d, caps=true) {

  locs = nema_screw_locs_2d(odd=false);
  h = nema_extension_l +nema_backplate_l - nema_screw_inset_h;

  for (v=locs) {

    translate(v) {
      translate([0,0,-nema_backplate_l]) {
        cylinder(d=d, h = h);
      }
      if (caps) {
        translate([0,0, nema_extension_l - nema_screw_inset_h]) {
          cylinder(h=nema_screw_inset_h, d=nema_screw_inset_d);
        }
      }
    }
  }
}



// color("grey") motor_body();
//color("silver") screw_extensions();

//cover();
module cover() {
  wall();
  color("silver") connector();
  color("green") pcb();
  pcb_bosses();
  color("pink") lid();
  feet();
}


print_cover();
module print_cover() {
  rotate([180,0,0]) {
    lid();
    wall();
    pcb_bosses();
    feet();
  }
}

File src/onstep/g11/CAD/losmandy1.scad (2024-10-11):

include <MCAD/motors.scad>

$fn = 100;


// standard properties nema 17 motor

nema_hole_sep = 31;		// dist between mounting holes
nema_pilot_d = 22;		// centration pilot diameter
nema_pilot_l = 2;		// centration pilot length
nema_screw_diam = 3;		// M3 mounting screws
nema_width = 42.3;		// width of motor face
nema_ROC = 5.5;			// ROC for corners of face
nema_shaft_d = 5;

// properties of our particular nema 17 motor

nema_len = 48;			// length of motor body
nema_shaft_len = 24;	// length of shaft protrusion from face
nema_dcut_len = 15;		// length of flatted part of shaft

// properties of Losmandy G11 mount

g11_shaft_gap = 6;		// dist betw shaft ends (motor and worm)
g11_worm_inset = 19.5;		// dist from plate edge to worm shaft end
g11_plate_thick = 8.4;		// thickness of g11 worm plate
g11_hole_sep = 47.65;		// dist betw mounting holes
g11_hole_offset = 12.7;		// dist from hole axis to motor axis
g11_screw_d = 0.1440 * 25.4;	// 6-32 clearance hole

// how far the motor shaft protrudes past the plate edge (in -z direction)
nema_protrusion = g11_worm_inset - g11_shaft_gap;
// how far the motor need to be spaced to achieve this (in +z direction)
nema_face_offset = nema_shaft_len - nema_protrusion;

plate_thick = nema_face_offset;


// properties of RJ45 adapter PCB (pin header in +y direction)

pcb_dx = 34;		// PCB size x
pcb_dy = 27.81;		// PCB size y
pcb_t = 1.57;		// PCB thickness
pcb_hole_dx =  28;	// hole sep in x
pcb_hole_dy = 11;	// hole sep in y
pcb_hole_y_off = 11.5;	// dist pin header edge to holes
pcb_screw_diam = 3;	// M3 hole (possibly 6-32?)
pcb_screw_clearance = 4;

// PCB location info

pcb_standoff = 10;	// height above mount plate
pcb_standoff_diam = 8;  // diameter of standoffs
pcb_nema_gap = 5;	// space betw pcb edge and motor

// lower part of plate will be a "deck" for 
//  adding connector adapter, lid, etc.

deck_thick = plate_thick;  //for now...?

// objects on top of the deck will use the following origin

deck_origin = [ 0, -nema_width/2 - pcb_nema_gap, deck_thick];

deck_dy = 40;
deck_dx = nema_width;

// RJ connector on PCB
rj_dx = 16;         // x size of metal box
//rj_dy = 16.6;       // y size of metal box
rj_dy = 17.0;       // y size of metal box
rj_dz = 16.5;       // z size of metal box
//rj_y_off = 10.75;   // edge of PCB to box
rj_y_off = 9.75;   // edge of PCB to box

             
rj_xy_loc = [0, - rj_y_off -rj_dy/2];

// cover for PCB is 3 sided box plus top

cov_wall_thick = 4; // thickness of walls
cov_dx = 42;        // x sep of wall midlines
cov_dy = 33;        // y sep of wall midlines
cov_ROC = 5;        // radius of curvature of wall centerline

cover_height = pcb_standoff + pcb_t + 0.5*rj_dz;

// Use a hull of circles to make a round-cornered rectangle. 
// Use delta for (small) changes in ROC.

module cover_shape_2d(delta=0) {
  // center of circles are inbound of defining corners
  xx = cov_dx/2 -cov_ROC;
  yy = cov_dy/2 -cov_ROC;
  center = [
             [ -xx-5, +yy],
             [ -xx, -yy],
             [ +xx, -yy],
             [ +xx+5, +yy]
  ];

  // modify ROC to keep center of circles constant
  ROC = cov_ROC + delta;
  translate([0, -cov_dy/2+ cov_wall_thick/2 + 0.5]) {
    hull() {
      for (c=center) {
        translate(c) {
          circle(r=ROC);
        }
      }
    }
  }
}

module wall_2d(thick=cov_wall_thick) {
  difference() {
    cover_shape_2d(delta=+thick/2);
    cover_shape_2d(delta=-thick/2);
  }
}

module wall() {
  difference() {
    linear_extrude(height=cover_height, convexity=10) {
      wall_2d();
      lid_holes_2d(diam=8);
    }
    translate([0,0,-.01]) {
      ridge(delta_w=0.1, delta_h=0.1);
      linear_extrude(height = cover_height+0.2) {
        lid_holes_2d();
      }
    }
  }
}

ridge_h = 1;
ridge_w = 1;

module ridge(delta_w=0, delta_h=0) {
  linear_extrude(height=ridge_h+delta_h)
    wall_2d(thick=ridge_w +delta_w);
}

module lid_holes_2d(diam=pcb_screw_diam){
  lh_x = 21.5;
  lh_y = -7;
  translate([ +lh_x, lh_y])
    circle(d=diam);
  translate([ -lh_x, lh_y])
    circle(d=diam);
}

module lid() {
  translate([0,0,cover_height - cov_wall_thick + 0.1]) {
    linear_extrude(height=cov_wall_thick) {
      difference() {
        cover_shape_2d();
        rj_conn_2d(dx=1, dy=1);
      }
    }
  }
}

module rj_conn() {
  translate([0,0,pcb_standoff+pcb_t]) {
    linear_extrude(height=rj_dz) {
      rj_conn_2d();
    }
  }
}

module rj_conn_2d(dx=0, dy=0){
  w=rj_dx + dx;
  h=rj_dy + dy;
    
  translate(rj_xy_loc) {
    square([w,h], center=true);       
  }
}

// calculate location of pcb center
pcb_loc = [0,
	   - pcb_dy/2,
	   pcb_standoff];

// calculate location of pcb holes center
pcb_hole_loc = [0,
		- pcb_hole_y_off - pcb_hole_dy/2,
		pcb_standoff];


// passage for wires along motor, into case
chim_dx = 5;
chim_dy= 3;
hole_dz = 6;
chim_ROC = 1;
module chimney() {
  translate([0, +cov_wall_thick, -0.1]) {
    linear_extrude(height=cover_height + 0.2) {
      hull() {
        xx = chim_dx/2 - chim_ROC;
        yy = chim_dy/2 - chim_ROC;
        translate([-xx, -yy]) circle(r=chim_ROC);
        translate([-xx, +yy]) circle(r=chim_ROC);
        translate([+xx, +yy]) circle(r=chim_ROC);
        translate([+xx, -yy]) circle(r=chim_ROC);
      }
    }
    cube([chim_dx, 2*cov_wall_thick, 2*hole_dz],
         center=true);
  }
}

///  MAIN OBJECT PLACEMENT


// CHOOSE OBJECTS TO DISPLAY (1=true, 0=false)

show_plate = 1;
show_cover = 1;
flip_cover = 0;   // use only if othjer objects hidden
show_extras = 1;

if (show_plate) {
  color("blue") plate();
}

if (show_cover) {
  if (flip_cover) {
    // place cover upside down for printing
    translate([0,0, cover_height]) {
      rotate([180,0,0]) {
        color("red") cover();
      }
    }
} else {
    translate(deck_origin) {
      color("red") cover();
    }
  }    
}

if (show_extras) {
  color("gray") motor();
  translate(deck_origin) {
    color("green") pcb();
    color("silver") rj_conn();
  }
}

module plate() {
  difference() {
    plate_blank();
    nema_screws();
    nema_pilot();
    mount_screws();
    translate([0, deck_origin.y, -0.01]) {
      linear_extrude(height = plate_thick + 0.02) {
        pcb_holes_2d(diam=pcb_screw_diam);
        lid_holes_2d(diam=pcb_screw_clearance);
      }
    }
  }
  translate(deck_origin + [0, 0, -.01]) {
    ridge(delta_w=-0.1);
    standoffs();
  }
}

module cover() {
    difference() {
      union() {
        wall();
        lid();
      }
      chimney();
    }
}


/*
rotate([180,0,0]) {
  wall();
  lid();
}
*/


module pcb_holes_2d(diam=pcb_screw_diam) {
  dx = pcb_hole_dx/2;
  dy = pcb_hole_dy/2;
  locs = [
	  [ +dx, +dy],
	  [ +dx, -dy],
	  [ -dx, -dy],
	  [ -dx, +dy]
	 ];
	  
  translate(pcb_hole_loc) {
    for (v=locs) {
      translate(v) {
	circle(d=diam);
      }
    }
  }
}
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

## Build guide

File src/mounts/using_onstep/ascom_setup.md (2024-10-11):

# Installing ASCOM for OnStep

## 1) Install ASCOM Platform

* Download the latest **ASCOM Platform** from the [ASCOM Downloads
  page](http://ascom-standards.com/Downloads/index.htm). You don't
  need any other downloads from the ASCOM website.

* If you have an older version of ASCOM Platform, it is best to
  uninstall it now.

* Install ASCOM Platform.  As part of this process, the installer will
  also download and install a compatible version of the Microsoft .NET
  software.

Now, any time you run an ASCOM-compliant program on your computer, it
will talk to this ASCOM Platform software to satisfy all of its
astronomical needs.

## 2) Install the OnStep ASCOM Driver

* Download the latest version of the [OnStep ASCOM unified 
  driver](http://stellarjourney.com/main/onstep-ascom-driver-software/).

* Install the driver.

Now, when someone asks the ASCOM software to do something OnStep-y, it
knows how to actually do it.

## A Quick Test

For now, we're just going to peek at the "OnStep Telescope Setup"
window to make sure the installation went okay.

* On your Desktop, there should be an icon for **ASCOM Diagnostics**.
  If not, use the Start Menu or search box to find it.

Note: There may be another Desktop icon called **ASCOM Profile
Explorer**.  Go ahead and delete that.

* Start the ASCOM Diagnostics program.

* Click **Choose Device --> Choose and Connect to Device**

* At the top left, use the **Select Device Type** selection box to
  choose **Telescope**.

* Click on **Choose**.  This will create a popup window called
  "Telescope Chooser."

* In the popup, click the selection box.  There should already be a
  few choices available, as ASCOM comes with simulators for most kinds
  of devices.

* Look at the available selections and make sure that **OnStep
  Telescope** is one of them.

* Not there?  Something has gone wrong.

* After selecting **Onstep Telescope**, click on **Properties**.  This
  will pop open a new window called **OnStep Telescope Setup**.

That's all we really need for now.  If you made it here, your ASCOM
software is properly installed and you are ready to observe.

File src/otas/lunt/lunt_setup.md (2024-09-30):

# Lunt Solar Scope Setup

## Prerequisites
* Mount is set up
* OTA installed in mount

## Setup Steps

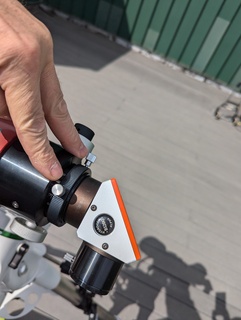
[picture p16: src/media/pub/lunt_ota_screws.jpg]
OTA screws

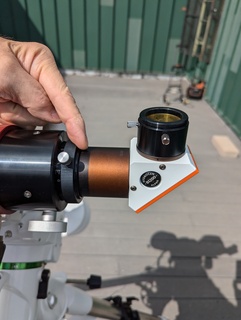
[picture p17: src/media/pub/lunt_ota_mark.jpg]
OTA mark


* The __draw tube__ (the moving part of the OTA) will need to be
  extended in order to achieve focus.
    - Locate the black knurled __draw tube ring__ near the diagonal.
    - Slightly loosen the two knurled silver __draw tube screws__ in the
      draw tube ring. This allows the diagonal to move freely.
    - Extend the diagonal an inch or two away from the scope.
    - Note the coloring of the diagonal input tube.  Near the diagonal it is
      "bronze".  Farther away, it is black.
    - Align the bronze/black boundary with the end of the draw tube ring.
      IOW, hide all of the black but none of the gold.
    - Tighten the two draw tube screws.
    - Hint: this is how you adjust the orientation of the eyepiece while
      observing.

* Insert the 25mm eyepiece.
* Unscrew the metal lens cover and store it in the aluminum case.
* The scope must now be balanced.  This is discussed in the section on mounts.

The solar scope is now ready for alignment and use.

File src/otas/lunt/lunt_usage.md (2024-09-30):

# Using the Lunt Solar Telescope.

## Prerequisites

  * OTA installed on mount
  * OTA setup complete.
  * OTA balanced.

## Alignment

For casual solar observing, precise alignment is not neccesary, but
the sun will drift out of view more quickly. When using the scope for
a group, it is best to put more effort into aligning the scope precisely.

### Basic Alignment

Basic alignment consists of mechanically adjusting the mount so that
the scope will track the sun.

* Align the mount __azimuth__ using a best guess of true north; e.g., parallel
  to walls of Barnes hall. 

* Align the mount __altitude__ using your known lattitude and the scale on
  the mount; e.g., adjust dial to 38.8 degrees for Colorado Springs.

* Power on the mount and enable solar tracking.

* Point the scope towards the sun either using the hand controller or by
  using the clutches and moving the scope manually.
  
* When you get close, look *at* (not into) the solar finder.  The
  sun will cast a shadow of the front disk onto the rear disk;
  i.e., the hole will create a bright spot of light on the rear
  disk. If the bright spot is not visible, use you hand or a piece of
  paper to find it.

* Using finer adjustments, move the scope until this spot is perfectly
  centered in the white circle of the rear finder disk.

* Look into the 25mm eyepiece and look for the sun.  You may need to move
  your head around to look off to the sides.

* Using the mount controls, fine-tune the pointing until the sun is centered.

### Improving Alignment

Alignment can be improved by adjusting the mount more carefully. But
another big help is using software-based alignment to model and
correct for mechanical imperfections.

The hand controller of the white (EQ6-R Pro) mount can do this, or you
can connect a Windows/Linux computer to the mount and run software
such as Stellarium.

Note that for solar observing, there are only two alignment targets
that you can use: the scope's __home position__ (always used by
default) and the sun.

* Precisely align the mount __azimuth__ using a compass (smartphone
  app).

* Precisely align the mount __altitude__ using an inclinometer
  (smartphone app.)

* Be sure the scope is very precisely in __home position__ when
  powering the mount on.

* Be sure to use correct data for observing site location, time, etc.  

* When you have the sun centered, use that point to update the alignment.

* Each time you re-center the scope on the Sun, use that point to
  update the software alignment.

* The tracking will improve more if the alignment points are widely
  separated.  For solar observing, that means using the sun at widely
  separated times. So set up the scope and start the alignment well in
  advance.

* Note that mounts have a __park__ feature.  When told to park, the
  scope slews to its home position and stores its software alignment
  data over a power cycle.  Thus, a preliminary alignment can be done
  well in advance, and the scope parked and powered off.  When powered
  on again the mount is already aligned, and one update on the sun's
  current position should provide a good improvement.

## Pressure tuning the H-alpha line.

The central wavelength of the solar scope's filter can be tuned very
slightly above or below the Hydrogen alpha wavelength by turning the
large brass knob on the side of the scope.  (The brass knob is just a
threaded piston, which changes the pressure inside of the etalon.)

The filter passes light in a very narrow range ( +/- 0.035 nm) above
or below this central wavelength.  This range is much smaller than the
Doppler shift of sunlight caused by motions of the Sun's surface.
Thus, using the brass knob, you can emphasize various parts of the
Sun's surface, depending on their motion towards/away from the Earth.

WARNING: If you unscrew the knob too far, it will come off.  Always
__hold onto it securely__ when loosening.

Here is a simple method for tuning the filter:

* Loosen the brass knob about 2 or 3 turns from where it was when you
  found it. Here we are assuming the previous user left the scope
  tuned to an interesting wavelength.

* Obtain a sharp visual focus of the part of the sun you are
  interested in; e.g., a prominence on the sun's limb, or the
  oatmeal-like texture of a central part of the solar disc.

* Gradually tighten the knob, watching for a change in contrast in the
  region of interest.  It shouldn't take too many turns to see a change.

Fun Fact: When using the solar scope with a camera, it is possible to
see brightening/darkening of opposite edges of the Sun due Doppler
shifts caused by the Sun's rotation.

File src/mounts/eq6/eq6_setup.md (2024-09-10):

# Setting up the Skywatcher ERQ6-R Pro Mount.

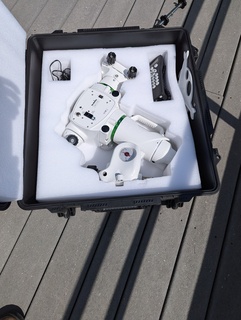
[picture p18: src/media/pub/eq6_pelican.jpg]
EQ6 in case.

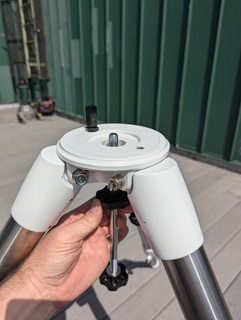
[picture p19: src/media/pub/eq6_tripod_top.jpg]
EQ6 tripod top.

* Set up the (white) EQ6-R Pro tripod.
  - Extend the legs about 10" or so and tighten to medium-snug.
  - Note the black chunk on top of the tripod. This is
    the __alignment post__.
  - Orient the tripod so that the alignment post is pointing North.
  - There is a vertical chrome bar beneath the tripod deck. The top end is
    threaded and should be free to rise up above the tripod deck; if not, screw
    the rod in until it becomes loose.

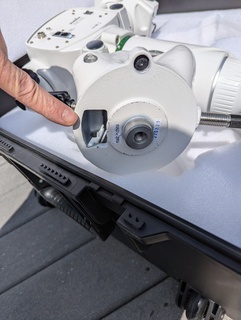
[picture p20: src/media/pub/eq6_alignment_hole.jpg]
EQ6 mount, alignment hole

* Prepare to install the mount
  - Lift the mount just few inches, rotate it slightly and rest it on the
    packing foam of the case.
  - If the mount is loose and floppy, reach under the central part of the mount
    and tighten the R.A. clutch lever. 
  - Look at the bottom mating surface of the mount and identify the
    __alignment hole__.

* Install the mount.
  - Lift the mount using the handle.
  - Orient the __alignment hole__ with the __alignment post__.
  - Place the mount gently on the tripod.
  - Use the upper knob on the vertical chrome bar to screw it medium tight
    into the mount. This will secure the mount to the tripod.

* Install the spider.
  - Remove the lower knob __and washer__ from the vertical chrome bar.
  - Install the spider, flat side up, onto the chrome bar.
  - Screw the lower knob __and washer__ about 1/2\" onto the chrome bar.
  - Adjust the spider so the 3 jaws engage the 3 tripod legs.
  - Turn the lower knob until it just starts to feel snug. Then lift the
    tripod legs one at a time and wiggle them a bit to ensure they are fully
    spread.
  - Now tighten the lower knob until it is medium tight.

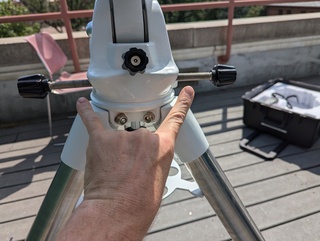
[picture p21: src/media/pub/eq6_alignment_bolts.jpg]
Alignment bolts

* Install azimuth adjuster bolts.
  - Locate the 2 adjuster bolts, and screw them slightly into the
    appropriate holes, adjacent to the tripod's alignment post.
  - Screw in the two bolts by equal amounts until you feel resistance in
    _both_ bolts.  The bolts should be snug, not tight.

* Level the mount.
  - Note the bubble level on the West side of the mount.
  - Adjust the length of the tripod legs one at a time until the bubble is
    centered.
  - Now tighten the tripod leg knobs to medium tight.

* Rough Alt alignment.
  - The mount has a pair of Alt (altitude) adjustment knobs right next to
    an Alt indicator dial.  Using the known lattitude of your observing site,
    adjust these knobs (loosen one, snug the other) until the Alt dial
    indicates your lattitude.

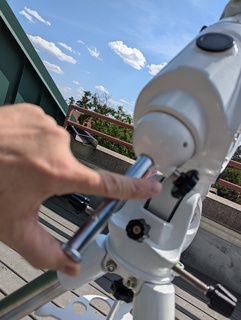
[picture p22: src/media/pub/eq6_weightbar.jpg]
Counterweight bar

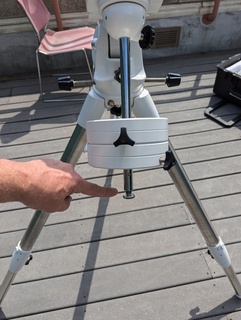
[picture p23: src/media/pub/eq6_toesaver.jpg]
Toe saver


* Add counter weights.
  - The __counterweight bar__ is a chrome bar that is stowed inside the mount.
    Loosen the small black knob on the north side of the mount and loosen it
    to extend the counterweight bar.  Gently snug the knob.
  - Identify the knurled __toe saver__ nut on the end of the counterweight bar.
    Remove it, but don't set it down.
  - Add the (white) counterweights and tighten them to the bar, near the
    bottom end.
    For a very small scope (e.g., the Lunt solar scope) you may only need one
    weight.
  - Replace the toe saver nut.

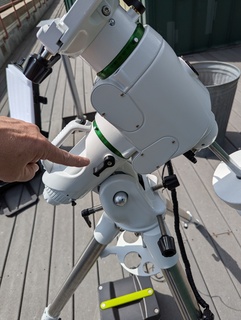
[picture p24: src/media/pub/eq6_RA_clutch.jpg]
RA clutch

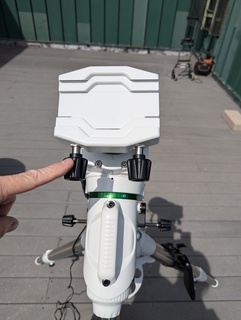
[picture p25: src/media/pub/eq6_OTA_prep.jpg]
saddle position


* Prepare mount for receiving OTA.
  - Each axis of the mount (RA and DEC) has a black clutch lever.  To adjust
    an axis, loosen the corresponding clutch, move the mount, and re-tighten.
  - The RA axis should already be oriented corectly.  If not, adjust it so
    the weight bar is pointing downward as much as possible.
  - Adjust the DEC axis so that the mount __saddle__ (the topmost part that
    holds the scope) is horizontal with the two black knobs pointing down.
  - Ensure that both clutches are snug so the mount does not move.

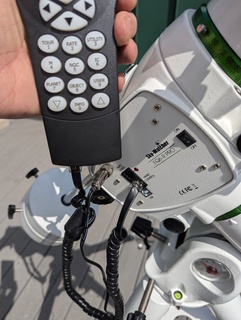
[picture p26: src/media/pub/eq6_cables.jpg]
HC and poer


* Hand control and Power.
  - Ensure that the power switch on the mount is turned off.
  - Insert and screw in the power cable and connect it to a 12V DC source.
    At present, this means a battery pack with a cigarette lighter socket.
  - Plug in the hand controller into the __Hand Control__ socket.

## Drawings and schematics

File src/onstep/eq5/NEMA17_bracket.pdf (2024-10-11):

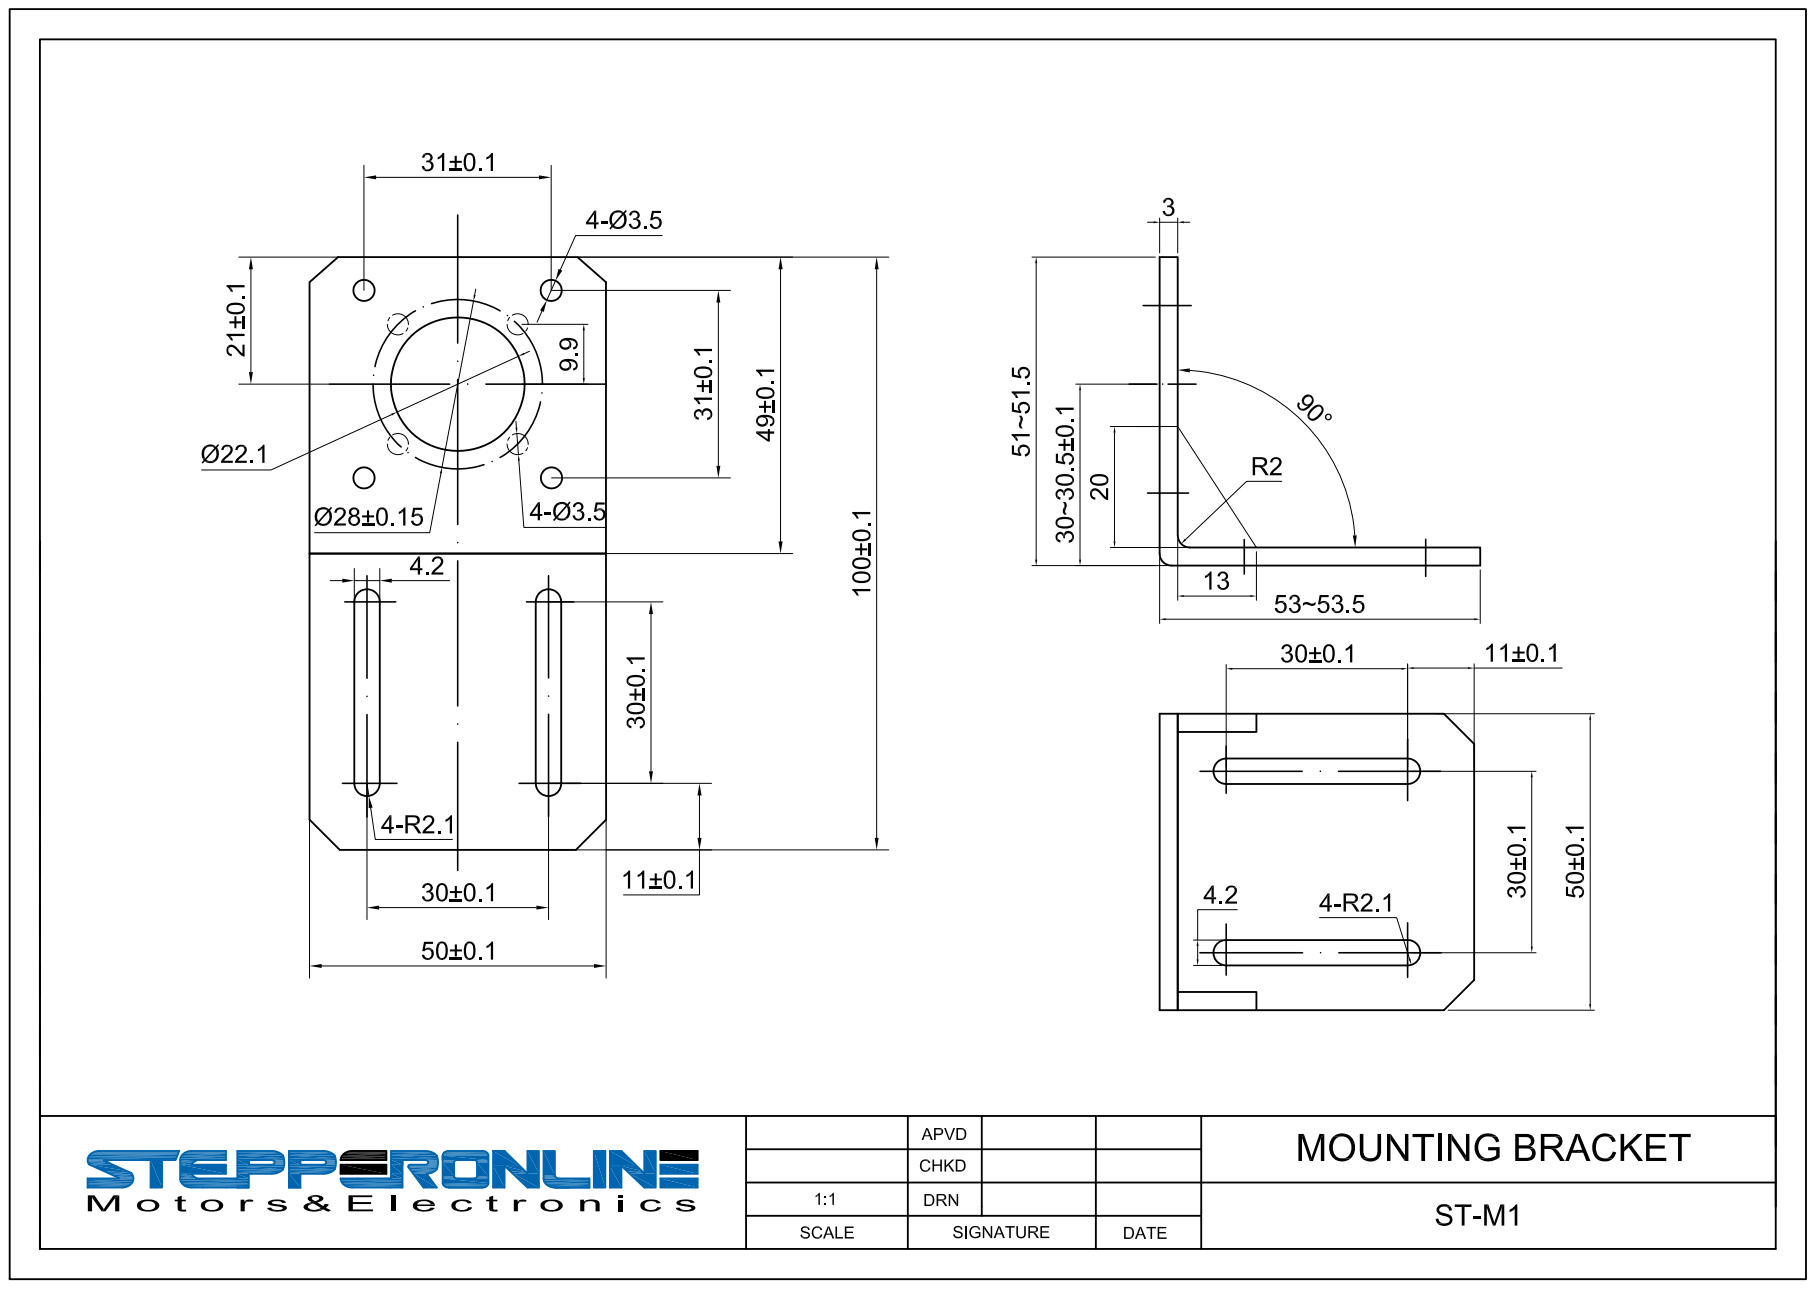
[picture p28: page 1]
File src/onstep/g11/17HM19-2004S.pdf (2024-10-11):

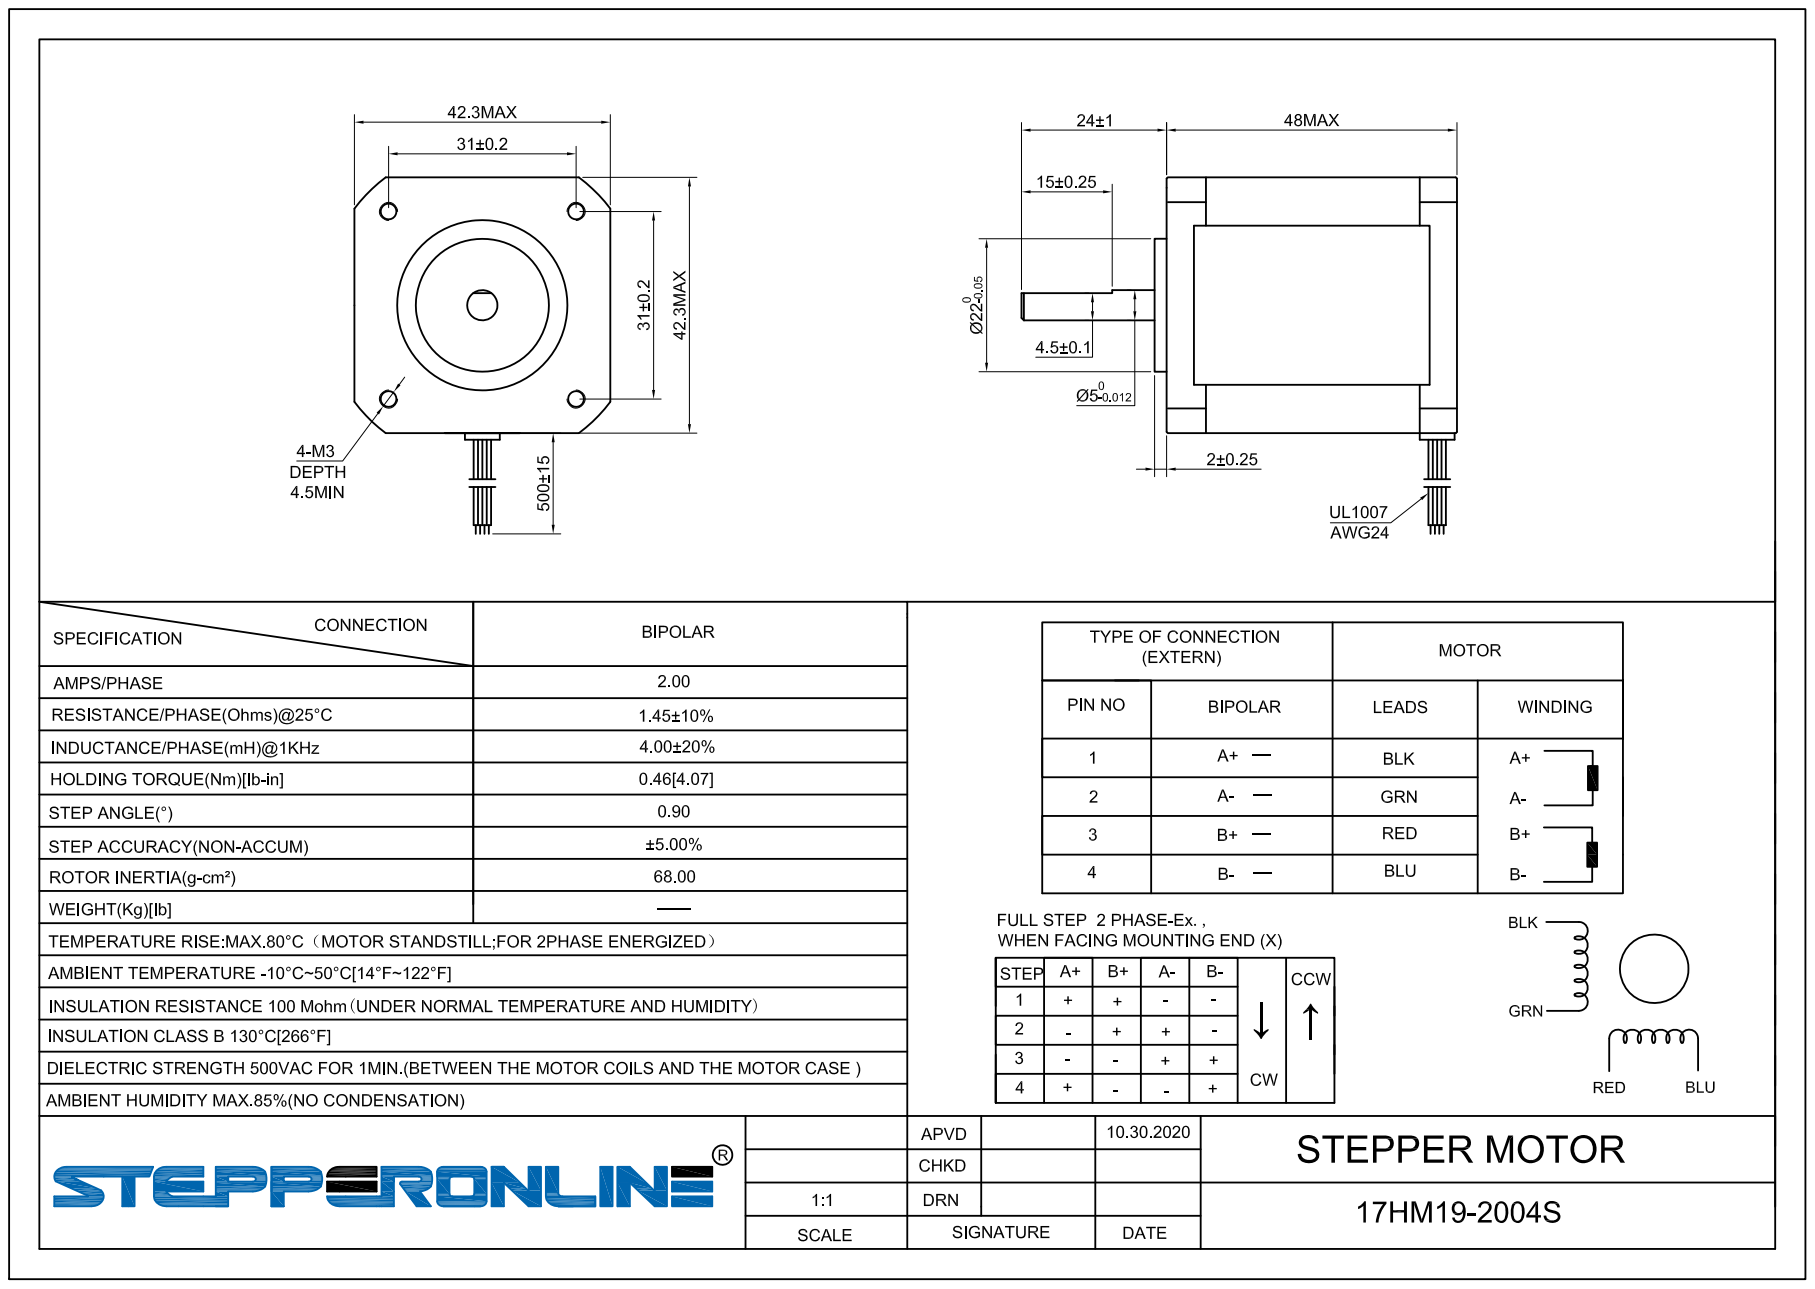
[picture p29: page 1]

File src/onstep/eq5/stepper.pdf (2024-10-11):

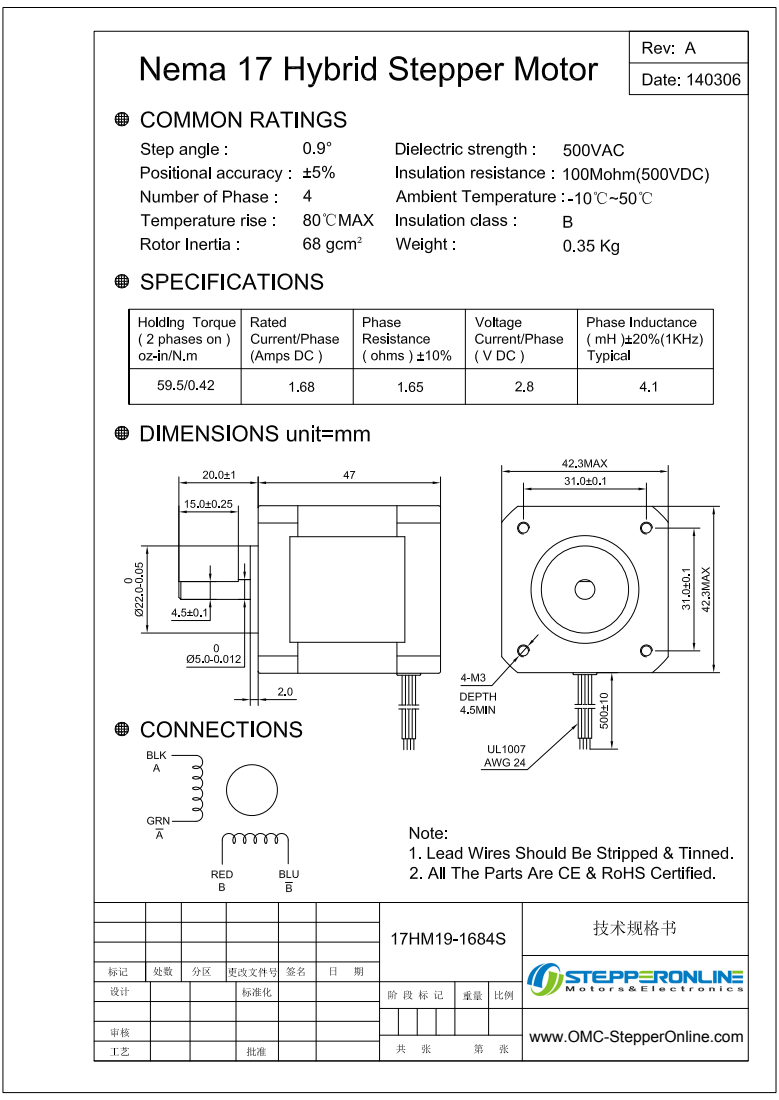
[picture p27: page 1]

www.OMC-StepperOnline.com
